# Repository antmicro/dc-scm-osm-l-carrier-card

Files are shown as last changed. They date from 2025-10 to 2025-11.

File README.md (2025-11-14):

# DC-SCM Carrier Card for OSM-L SoMs

Copyright (c) 2025 [Antmicro](https://www.antmicro.com)




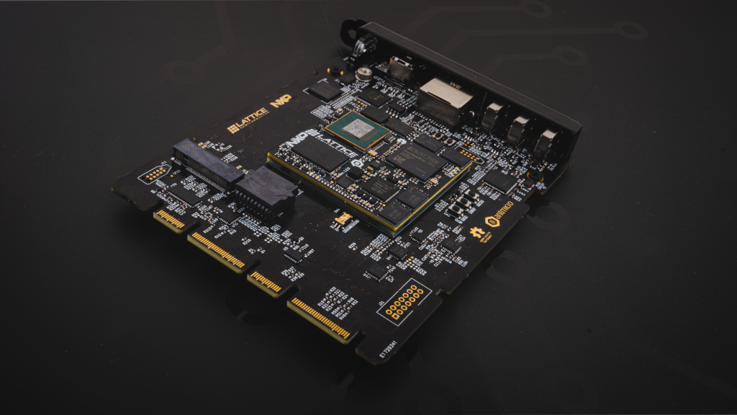
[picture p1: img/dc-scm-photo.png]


## Overview

This project includes open hardware design files for a DC-SCM compliant PCB that supports System on Modules following the [OSM-L](https://sget.org/standards/osm/) standard specified by the SGet group.
The DC-SCM follows the interface and mechanical outline described in the 2.1 revision of the [DC-SCM standard](https://drive.google.com/file/d/1-SdSQvSWy5pNN_kBiyztblxE4jdyUe9W/view?usp=sharing) specified by the Open Compute Project community.
Apart from establishing a base DC-SCM compliant platform, the design includes a series of breakout connectors, jumpers and other supplementary circuitry for developing BMC software features for security, reliability, commissioning and benchmarking.

This DC-SCM card has been designed as a carrier board to an L-sized [OSM design](https://github.com/antmicro/osm-l-bmc-som) that combines a Lattice FPGA and an NXP i.MX943 series Application Processor (AP).

The PCB design files were prepared in [KiCad](kicad.org/download) 9.x

## Key features

* Landing pad for OSM-L type of SoM
* Realtek 1Gb Ethernet PHY (Realtek [RTL8211FDI-CG](https://openhardware.antmicro.com/components/realtek-rtl8211fdi-cg))
* ITE [IT6251](https://openhardware.antmicro.com/components/ite-tech-it6251) LVDS-DisplayPort bridge
* USB-C port with FTDI [FT4232H](https://openhardware.antmicro.com/components/ftdi-chip-ft4232h-56q-reel/) for SoM debug and software integration
* USB-C port connected to the OSM-L SoM pads
* USB-C port connected to the HPM
* M.2 (key-M) expansion slot connected to the HPM
* Slot for removable BIOS memories connected directly to the HPM
* Optional on-board TPM connector

## Project structure

The main directory contains KiCad PCB project files, a LICENSE and a README.
The remaining files are stored in the following directories:

* `doc` - contains board schematic
* `img` contains graphics for this README

## Licensing

This project is published under the [Apache-2.0](LICENSE) license.

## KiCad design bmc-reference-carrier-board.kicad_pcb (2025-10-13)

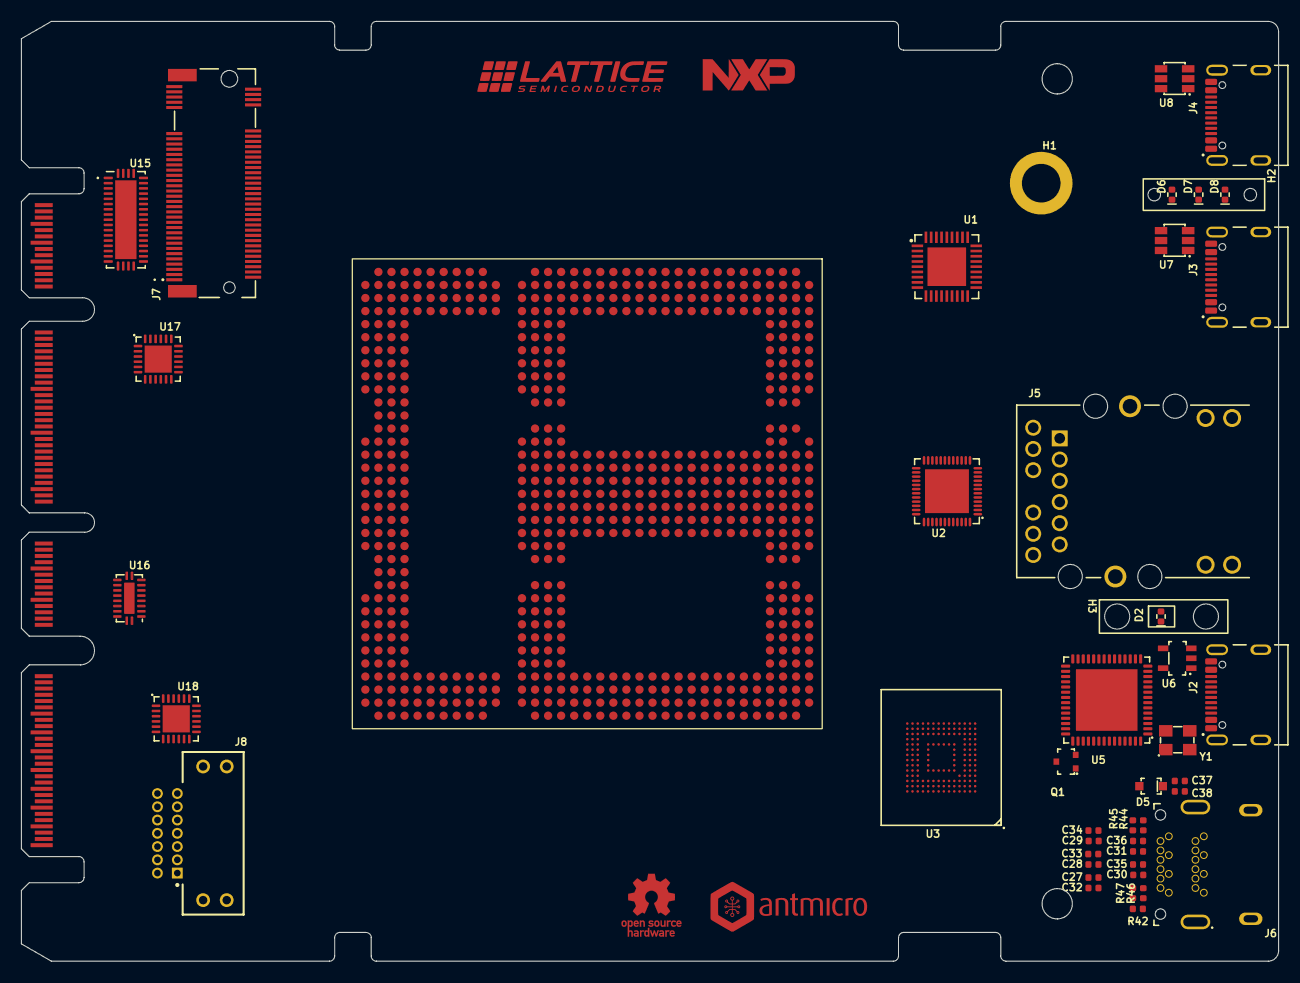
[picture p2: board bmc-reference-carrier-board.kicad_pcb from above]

Board: 8 copper layers, 120.4 x 90.0 mm, 47 parts (0 on the bottom side), 64 nets, no tracks yet.

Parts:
C27, C28, C29, C30, C31, C32, C33, C34, C35, C36: C_100n_0402; C_0402_1005Metric
C37, C38: C_4u7_6.3V_0402; C_0402_1005Metric
D2, D6, D7, D8: LED_G_0402_VLMTG1500-GS08; LED_0402_1005Metric_G
D5: 1N4148WS-7-F; D_SOD-323
H1: Spacer_Drill3.7mm_H2.5mm_9774025151R
H2: Lightpipe_Mentor_1296.2013; Mech_Lightpipe_Mentor_1296.2013
H3: Lightpipe_Mentor_1271.1000; Mech_Lightpipe_Mentor_1271.1000
J1: PCB-Edge_DC-SCM-2.1_2x84_Rev-1-1; PCB-Edge_DC-SCM_2x84_Rev-1-0
J2, J3, J4: USB-C_GCT_USB4105-GF-A; USB-C_Receptacle_GCT_USB4105-GF-A
J5: L834-1G1T-S7; RJ45_BEL_L834-1G1T-S7
J6: DisplayPort-Mini_TE_2129320-3; DisplayPort-Mini_Receptacle_TE_2129320-3
J7: Bus_M.2_1-2199230-6; Bus_M.2_Socket_Key_M_TE_1-2199230-6
J8: TFM-107-01-X-D-RE1-WT; Socket_Samtec_TFM_2x7_TFM-107-01-X-D-RE1-WT
Q1: BSS84AKW; SOT-323
R42: R_51k_0402; R_0402_1005Metric
R44, R45: R_100k_0402; R_0402_1005Metric
R46, R47: R_1M_0402; R_0402_1005Metric
U1: USB2514B-I_M2; QFN-36-1EP_6x6mm_P0.5mm_EP3.7x3.7mm
U2: RTL8211FS-CG; QFN-48-1EP_6x6mm
U3: SDINBDG4-8G; BGA-196-153_11.5x13mm_Layout14x14_P0.5x0.5mm
U5: FT4232H_VQFN; QFN-56-1EP_8x8mm_P0.5mm
U6: NCP718BSN330T1G; SOT-23-5
U7, U8: AP22615A_TSOT26; TSOT23-6
U14: OSM-L_Carrier-side
U15: TMUXHS4412RUAR; WQFN-42-1EP_3.5x9mm_P0.5mm
U16: TMUXHS4212IRKSR; VQFN-20_1EP_4.5x2.5mm_P0.5mm
U17, U18: TS3A27518E_QFN; QFN-24-1EP_4x4mm_P0.5mm_EP2.6x2.6mm
Y1: Resonator_12MHz_ABM8G; Resonator_SMD_Abracon_ABM8G_3.2x2.5mm

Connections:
+5V: U7.6 (IN), U8.6 (IN)
/DC-SCM 2.1 connector/DC_SCM_12V_AUX: J1.A1 (P12V_AUX), J1.A2 (P12V_AUX), J1.A3 (P12V_AUX), J1.A4 (P12V_AUX)
/DC-SCM 2.1 connector/DC_SCM_P3V0: J1.B28 (P3V0_HPM_SCM_BAT), U14.W17 (RTC_PWR)
/DC-SCM 2.1 connector/DC_SCM_PRSNT0_N: J1.A7 (PRSNT1_HPM_SCM_N), J1.B58 (PRSNT0_SCM_HPM_N)
/DC-SCM 2.1 connector/DC_SCM_USB1.D+: J3.A6 (D_{A}+), J3.B6 (D_{B}+)
/DC-SCM 2.1 connector/DC_SCM_USB1.D-: J3.A7 (D_{A}-), J3.B7 (D_{B}-)
/Ethernet PHY/ETHERNET.MDI0+: J5.11 (TRD1+), U2.2 (MDIP0)
/Ethernet PHY/ETHERNET.MDI0-: J5.10 (TRD1-), U2.3 (MDIN0)
/Ethernet PHY/ETHERNET.MDI1+: J5.4 (TRD2+), U2.5 (MDIP1)
/Ethernet PHY/ETHERNET.MDI1-: J5.5 (TRD2-), U2.6 (MDIN1)
/Ethernet PHY/ETHERNET.MDI2+: J5.3 (TRD3+), U2.7 (MDIP2)
/Ethernet PHY/ETHERNET.MDI2-: J5.2 (TRD3-), U2.8 (MDIN2)
/Ethernet PHY/ETHERNET.MDI3+: J5.8 (TRD4+), U2.10 (MDIP3)
/Ethernet PHY/ETHERNET.MDI3-: J5.9 (TRD4-), U2.11 (MDIN3)
/Front panel USB/FTDI_3V3: Q1.2 (S), U5.16 (V_{CCIO}), U5.36 (V_{CCIO}), U5.44 (V_{REGIN}), U5.50 (V_{CCIO}), U6.5 (VOUT)
/Front panel USB/USB0_VBUS: J3.A4 (VBUS), J3.A9 (VBUS), J3.B4 (VBUS), J3.B9 (VBUS), U7.1 (OUT)
/Front panel USB/USB1.D+: J4.A6 (D_{A}+), J4.B6 (D_{B}+)
/Front panel USB/USB1.D-: J4.A7 (D_{A}-), J4.B7 (D_{B}-)
/Front panel USB/USB1_VBUS: J4.A4 (VBUS), J4.A9 (VBUS), J4.B4 (VBUS), J4.B9 (VBUS), U8.1 (OUT)
/Front panel USB/USB2_D+: J2.A6 (D_{A}+), J2.B6 (D_{B}+), U5.8 (D+)
/Front panel USB/USB2_D-: J2.A7 (D_{A}-), J2.B7 (D_{B}-), U5.7 (D-)
/Front panel USB/USB2_VBUS: J2.A4 (VBUS), J2.A9 (VBUS), J2.B4 (VBUS), J2.B9 (VBUS), U6.1 (VIN), U6.3 (EN)
/Front panel USB/VCORE: U5.2 (V_{CORE}), U5.31 (V_{CORE}), U5.43 (V_{REGOUT})
/Front panel USB/XI: U5.3 (OSCI), Y1.1
/Front panel USB/XO: U5.4 (OSCO), Y1.3
/Front panel Video/AUX+: C31.1, J6.16 (AUX+), R45.2
/Front panel Video/AUX-: C36.1, J6.18 (AUX-), R44.1
/Front panel Video/CFG1: J6.4 (CFG1), R46.2
/Front panel Video/CFG2: J6.6 (CFG2), R47.2
/Front panel Video/DP_PWR: C37.2, C38.2, D5.1 (C), J6.20 (DP_PWR), R44.2
/Front panel Video/HPD: J6.2 (HPD), R42.1
/Front panel Video/TXD0+: C27.1, J6.3 (TXD0+)
/Front panel Video/TXD0-: C32.1, J6.5 (TXD0-)
/Front panel Video/TXD1+: C28.1, J6.9 (TXD1+)
/Front panel Video/TXD1-: C33.1, J6.11 (TXD1-)
/Front panel Video/TXD2+: C29.1, J6.15 (TXD2+)
/Front panel Video/TXD2-: C34.1, J6.17 (TXD2-)
/Front panel Video/TXD3+: C30.1, J6.10 (TXD3+)
/Front panel Video/TXD3-: C35.1, J6.12 (TXD3-)
/PCIe - SGMII Mux/PCIE_x4.RX1+: J7.31 (PER1_P), U15.34 (DA1P)
/PCIe - SGMII Mux/PCIE_x4.RX1-: J7.29 (PER1_N), U15.33 (DA1N)
/PCIe - SGMII Mux/PCIE_x4.RX2+: J7.19 (PER2_P), U15.25 (DA3P)
/PCIe - SGMII Mux/PCIE_x4.RX2-: J7.17 (PER2_N), U15.24 (DA3N)
/PCIe - SGMII Mux/PCIE_x4.TX1+: J7.37 (PET1_P), U15.38 (DA0P)
/PCIe - SGMII Mux/PCIE_x4.TX1-: J7.35 (PET1_N), U15.37 (DA0N)
/PCIe - SGMII Mux/PCIE_x4.TX2+: J7.25 (PET2_P), U15.29 (DA2P)
/PCIe - SGMII Mux/PCIE_x4.TX2-: J7.23 (PET2_N), U15.28 (DA2N)
/PCIe - SGMII Mux/VCC: U15.5 (VCC), U15.13 (VCC)
GND: C37.1, C38.1, J1.A5 (GND), J1.A6 (GND), J1.A19 (GND), J1.A22 (GND), J1.A25 (GND), J1.A29 (GND), J1.A32 (GND), J1.A35 (GND), J1.A38 (GND), J1.A53 (GND), J1.A64 (GND), J1.A67 (GND), J1.A70 (GND), J1.B11 (GND), J1.B19 (GND), J1.B22 (GND), J1.B25 (GND), J1.B29 (GND), J1.B32 (GND), J1.B35 (GND), J1.B38 (GND), J1.B64 (GND), J1.B67 (GND), J1.B70 (GND), J1.OA1 (GND), J1.OA4 (GND), J1.OA7 (GND), J1.OA10 (GND), J1.OA13 (GND), J1.OB1 (GND), J1.OB4 (GND), J1.OB7 (GND), J1.OB10 (GND), J1.OB13 (GND), J2.A1 (GND), J2.A12 (GND), J2.B1 (GND), J2.B12 (GND), J3.A1 (GND), J3.A12 (GND), J3.B1 (GND), J3.B12 (GND), J4.A1 (GND), J4.A12 (GND), J4.B1 (GND), J4.B12 (GND), J6.1 (GND), J6.7 (GND), J6.8 (GND), J6.13 (GND), J6.14 (GND), J6.19 (GND), J6.SH, R45.1, R46.1, R47.1, U3.A6 (VSS), U3.C4 (VSSQ), U3.E7 (VSS), U3.G5 (VSS), U3.H10 (VSS), U3.J5 (VSS), U3.K8 (VSS), U3.N2 (VSSQ), U3.N5 (VSSQ), U3.P4 (VSSQ), U3.P6 (VSSQ), U5.10 (TEST), U5.21 (GND), U5.41 (GND), U5.45 (GND), U5.57 (GND), U6.2 (GND), U7.2 (GND), U8.2 (GND), U15.6 (GND), U15.9 (GND), U15.16 (GND), U15.21 (GND), U15.30 (GND), U15.39 (GND), U15.43 (GND), U16.5 (GND), U16.11 (GND), U16.20 (GND), U16.21 (GND), Y1.2 (SH), Y1.4 (SH)
unnamed: D2.2 (A), Q1.3 (D)
unnamed: J5.1 (TRCT3), J5.6 (TRCT2), J5.7 (TRCT4), J5.12 (TRCT1)
unnamed: J7.2 (3V3), J7.4 (3V3), J7.12 (3V3), J7.14 (3V3), J7.16 (3V3), J7.18 (3V3), J7.70 (3V3), J7.72 (3V3), J7.74 (3V3)
unnamed: J7.1 (GND), J7.3 (GND), J7.9 (GND), J7.15 (GND), J7.21 (GND), J7.27 (GND), J7.33 (GND), J7.39 (GND), J7.45 (GND), J7.51 (GND), J7.57 (GND), J7.71 (GND), J7.73 (GND), J7.75 (GND)
unnamed: J7.MP1 (MP), J7.MP2 (MP)
unnamed: Q1.1 (G), U5.54 (~PWR_{EN})
unnamed: U1.15 (VDD33), U1.23 (VDD33)
unnamed: U1.5 (VDDA33), U1.10 (VDDA33), U1.29 (VDDA33), U1.36 (VDDA33)
unnamed: U2.4 (AVDD10), U2.9 (AVDD10), U2.47 (AVDD10)
unnamed: U2.1 (AVDD33), U2.12 (AVDD33), U2.30 (AVDD33)
unnamed: U3.E6 (VCC), U3.F5 (VCC), U3.J10 (VCC), U3.K9 (VCC)
unnamed: U3.C6 (VCCQ), U3.M4 (VCCQ), U3.N4 (VCCQ), U3.P3 (VCCQ), U3.P5 (VCCQ)
unnamed: U14.A4 (GND), U14.A7 (GND), U14.A10 (GND), U14.A26 (GND), U14.A29 (GND), U14.A32 (GND), U14.AA1 (GND), U14.AA4 (GND), U14.AA7 (GND), U14.AA8 (GND), U14.AA10 (GND), U14.AA11 (GND), U14.AA14 (GND), U14.AA17 (GND), U14.AA19 (GND), U14.AA22 (GND), U14.AA25 (GND), U14.AA26 (GND), U14.AA27 (GND), U14.AA28 (GND), U14.AA32 (GND), U14.AB3 (GND), U14.AB6 (GND), U14.AB9 (GND), U14.AB15 (GND), U14.AB21 (GND), U14.AB28 (GND), U14.AB31 (GND), U14.AB34 (GND), U14.AC4 (GND), U14.AC7 (GND), U14.AC10 (GND), U14.AC27 (GND), U14.AC30 (GND), U14.AC33 (GND), U14.AE2 (GND), U14.AE34 (GND), U14.AF35 (GND), U14.AG3 (GND), U14.AH2 (GND), U14.AH34 (GND), U14.AJ35 (GND), U14.AK3 (GND), U14.AL2 (GND), U14.AL34 (GND), U14.AM13 (GND), U14.AM16 (GND), U14.AM19 (GND), U14.AM22 (GND), U14.AM35 (GND), U14.AN3 (GND), U14.AN6 (GND), U14.AN9 (GND), U14.AN11 (GND), U14.AN15 (GND), U14.AN18 (GND), U14.AN21 (GND), U14.AN33 (GND), U14.AP2 (GND), U14.AP5 (GND), U14.AP8 (GND), U14.AP13 (GND), U14.AP16 (GND), U14.AP19 (GND), U14.AP22 (GND), U14.AP25 (GND), U14.AP28 (GND), U14.AP31 (GND), U14.AP34 (GND), U14.AR14 (GND), U14.AR17 (GND), U14.AR20 (GND), U14.AR26 (GND), U14.AR29 (GND), U14.AR32 (GND), U14.B2 (GND), U14.B5 (GND), U14.B8 (GND), U14.B9 (GND), U14.B27 (GND), U14.B28 (GND), U14.B30 (GND), U14.B33 (GND), U14.C11 (GND), U14.C25 (GND), U14.C32 (GND), U14.C35 (GND), U14.D1 (GND), U14.D5 (GND), U14.D8 (GND), U14.D18 (GND), U14.D28 (GND), U14.D34 (GND), U14.E2 (GND), U14.E15 (GND), U14.E21 (GND), U14.F16 (GND), U14.F20 (GND), U14.F33 (GND), U14.F35 (GND), U14.G34 (GND), U14.H2 (GND), U14.H4 (GND), U14.H32 (GND), U14.J16 (GND), U14.J20 (GND), U14.J33 (GND), U14.J35 (GND), U14.K32 (GND), U14.K34 (GND), U14.L2 (GND), U14.L4 (GND), U14.L18 (GND), U14.M16 (GND), U14.M20 (GND), U14.M32 (GND), U14.M35 (GND), U14.N34 (GND), U14.P2 (GND), U14.P4 (GND), U14.P18 (GND), U14.R1 (GND), U14.R16 (GND), U14.R20 (GND), U14.R32 (GND), U14.T34 (GND), U14.U2 (GND), U14.U4 (GND), U14.V1 (GND), U14.V16 (GND), U14.V20 (GND), U14.W3 (GND), U14.W34 (GND), U14.Y2 (GND), U14.Y18 (GND)
unnamed: U14.AE4 (VCC_IN_5V), U14.AF4 (VCC_IN_5V), U14.AG4 (VCC_IN_5V), U14.AH3 (VCC_IN_5V), U14.AH4 (VCC_IN_5V), U14.AJ3 (VCC_IN_5V), U14.AJ4 (VCC_IN_5V), U14.AK4 (VCC_IN_5V), U14.Y8 (VCC_IN_5V), U14.Y9 (VCC_IN_5V), U14.Y10 (VCC_IN_5V), U14.Y11 (VCC_IN_5V), U14.Y17 (VCC_IN_5V), U14.Y25 (VCC_IN_5V), U14.Y26 (VCC_IN_5V), U14.Y27 (VCC_IN_5V), U14.Y28 (VCC_IN_5V)
unnamed: U14.AA18 (V_BAT), U14.AB18 (V_BAT)

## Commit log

2025-08-19 [#81876] Create KiCad file structure. Define DC-SCM 2.1 edge and outline
    [bmc-reference-carrier-board.kicad_pcb, bmc-reference-carrier-board.kicad_sch, dc-scm-connector.kicad_sch]
2025-08-19 [#81876] Add component and tracks keepout as defined in DC-SCM 2.1 spec
    [bmc-reference-carrier-board.kicad_pcb]
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2025-10-13 [#81876] Update date, Regroup OSM L block to make it interchangeable
    [bmc-reference-carrier-board.kicad_sch, dc-scm-connector.kicad_sch, dsi-to-dp-converter.kicad_sch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]
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2025-10-13 [#81978] Fix subsheet file naming
    [bmc-reference-carrier-board.kicad_sch, front-panel-low-speed.kicad_sch, front-panel-usb.kicad_sch]
2025-10-13 [#81876] Replace OSM blocks with single A2 sheet
    [bmc-reference-carrier-board.kicad_sch, osm-l.kicad_sch, osm_l.kicad_sch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]
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2025-10-13 [#81876] Hierarchical design review fixes
    [bmc-reference-carrier-board.kicad_sch, dsi-to-dp-converter.kicad_sch, lvds-to-dp-converter.kicad_sch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]
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2025-10-13 [#82153] Move Ethernet bus definition to root schematic
    [bmc-reference-carrier-board.kicad_sch, front-panel-ethernet.kicad_sch]
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2025-10-13 [#81876] Join sheets: Front panel USB and Front panel Low Speed
    [bmc-reference-carrier-board.kicad_sch, front-panel-low-speed.kicad_sch, front-panel-usb.kicad_sch]
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2025-10-13 [#82153] Fix LED2 label on ETH sheet
    [front-panel-ethernet.kicad_sch]
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2025-10-13 [#82157] Labels on root sheet from Ethernet and video sheets
    [bmc-reference-carrier-board.kicad_sch]
2025-10-13 [#81876] Add bus definitions for JTAG and UART
    [front-panel-usb.kicad_sch]
2025-10-13 [#81876] Add FTDI chip, DBG USB and LDO
    [front-panel-usb.kicad_sch]
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2025-10-13 [#82157] Move JTAG and UART definitions to root sheet
    [bmc-reference-carrier-board.kicad_sch, front-panel-usb.kicad_sch]
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2025-10-13 [#82176] Fix conflicting annotations
    [emmc.kicad_sch, eth-phy.kicad_sch, front-panel-ethernet.kicad_sch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]
2025-10-13 [#82176] Add bus definitions for PCIe and USB SS
    [bmc-reference-carrier-board.kicad_sch]
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2025-10-13 [#82148] Replace PCIe/USB mux with TMUXHS4212IRKSR
    Update PCIe/USB mux sheet
    [pcie-usb-mux.kicad_sch]
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2025-10-13 Replace {slash} with _
    [dc-scm-connector.kicad_sch]
2025-10-13 [#82226] Extend PCIe bus definition to x4. Update hierarchical pins
    [bmc-reference-carrier-board.kicad_sch]
2025-10-13 [#82226] Add PCIe connection to PCIe x4 connector
    [pcie-x4-connector.kicad_sch]
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2025-10-13 Replace USB-C connectors with vertical version
    [front-panel-usb.kicad_sch]
2025-10-13 Replace Eth connector with 7498111120R
    [bmc-reference-carrier-board.kicad_sch, front-panel-ethernet.kicad_sch]
2025-10-13 Replace Mini DP connector with E9320-001-01
    [front-panel-video.kicad_sch]
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2025-10-13 Change USB0 and USB1 to advertise as 500mA source
    [front-panel-usb.kicad_sch]
2025-10-13 [#82176] Import components from schematic and create initial placement
    [bmc-reference-carrier-board.kicad_pcb]
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2025-10-13 [#82323] Add IxC, LTPI, SGMII, RGMII, SPI, eSPI, QSPI buses definitions
    [bmc-reference-carrier-board.kicad_sch]
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2025-10-13 [#82323] Connect NC-SI, QSPI, LTPI and UART buses to DC-SCM
    [dc-scm-connector.kicad_sch]
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2025-10-13 [#82323] Connect JTAG, USB, TPM, IxC and SPI buses to DC-SCM
    [dc-scm-connector.kicad_sch]
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2025-10-13 [#82323] Connect SDIO to OSM, prepare LVDS connections
    [osm-l.kicad_sch]
2025-10-13 [#82323] Update OSM connections
    Move LTPI to LVSD pins
    Move I2C 0/1/2/3 lanes to vendor defined pins
    Move I2C/I3C 16/17 to GPIOD
    Add ~PRSNT1 as GPIO_A_3
    Add ~IRQ0 as GPIO_A_2
    Add ~STDB_RDY as GPIO_A_1
    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
    [osm-l.kicad_sch]
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2025-10-13 [#82341] LVDS/DP Bridge: Add 1V2 and 1V8 LDOs
    [lvds-to-dp-converter.kicad_sch]
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2025-10-13 [#83147] Fix spi labels
    [lvds-to-dp-converter.kicad_sch, osm-l.kicad_sch]
2025-10-13 [#83146] Fix LTPI connection, add bias
    [bmc-reference-carrier-board.kicad_sch, ltpi-voltage-bias.kicad_sch, lvds-to-dp-converter.kicad_sch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]
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2025-10-13 [#82233] Added eSPI/QSPI mux and DNP QSPI flash memory
    [bios_qspi.kicad_sch, bmc-reference-carrier-board.kicad_sch, espi-qspi-mux.kicad_sch]
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2025-10-13 [#82176] eMMC: change chip to 32GB & add decoupling
    [bmc-reference-carrier-board.kicad_sch, emmc.kicad_sch]
2025-10-13 [#82176] Connect eMMC SDIO to OSM, annotate eMMC schematic
    [bmc-reference-carrier-board.kicad_sch, emmc.kicad_sch, osm-l.kicad_sch]
2025-10-13 [#83148] Add level shifters for i2c & stby
    [dc-scm-connector.kicad_sch, i2c_level_shifters.kicad_sch, stby_level_shifters.kicad_sch]
2025-10-13 [#83148] Connect the level shifters, change STBY bus to individual signals
    [bmc-reference-carrier-board.kicad_sch, dc-scm-connector.kicad_sch, i2c_level_shifters.kicad_sch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]
2025-10-13 Changed A4 sheets to A3 and cleaned them up
    [espi-qspi-mux.kicad_sch, front-panel-ethernet.kicad_sch, i2c_level_shifters.kicad_sch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]
2025-10-13 [#83363] Replaced 1V8 LDO with DC/DC and moved it to power sheet
    [lvds-to-dp-converter.kicad_sch, power.kicad_sch]
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2025-10-13 [#83338] Fixed PCIe TX/RX
    [dc-scm-connector.kicad_sch, pcie-sgmii-mux.kicad_sch, pcie-x4-connector.kicad_sch]
2025-10-13 [#83338] Fixed HS connection AC caps and TX/RX swaps
    [bmc-reference-carrier-board.kicad_sch, dc-scm-connector.kicad_sch, osm-l.kicad_sch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]
2025-10-13 [#83329] Connect LEDs, crystal resontor, MDIO and MDC to the ETH PHY
    [eth-phy.kicad_sch]
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2025-10-13 [#83329] Change ETH PHY IC from RTL8211FS-CG to RTL8211FDI-CG
    [eth-phy.kicad_sch]
2025-10-13 [#83329] Finish connecting ETH PHY, connect ETH LEDs, adjust PHY power supply filtering
    [eth-phy.kicad_sch, front-panel-ethernet.kicad_sch]
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2025-10-13 [#83329] Small ethernet PHY fixes
    [bmc-reference-carrier-board.kicad_sch, eth-phy.kicad_sch, front-panel-ethernet.kicad_sch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]
2025-10-13 [#83331] Added PECI circuitry. Small top fixes
    [bmc-reference-carrier-board.kicad_sch, dc-scm-connector.kicad_sch, eth-phy.kicad_sch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]
2025-10-13 [#83335] Change TPM connector to 2x7 pin header and connect it
    [tpm.kicad_sch]
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2025-10-13 [#83336] Small front panel interface fixes
    [bmc-reference-carrier-board.kicad_sch, espi-qspi-mux.kicad_sch, front-panel-ethernet.kicad_sch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]
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2025-10-13 [#82323] Small OSM pinout fixes
    [bmc-reference-carrier-board.kicad_sch, osm-l.kicad_sch]
2025-10-13 [#83362] Add headers to LTPI, PECI and I2C
    [dc-scm-connector.kicad_sch]
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2025-10-13 [#83362] Fix connections of headers, add I2C mux
    [bmc-reference-carrier-board.kicad_sch, dc-scm-connector.kicad_sch, fpga-devkit-conn.kicad_sch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]
2025-10-13 [#83362] Remove bad NC marks, small visual fixes
    [fpga-devkit-conn.kicad_sch]
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2025-10-13 [#83652] Add ability to program BIOS SPI flash
    [bios_qspi.kicad_sch, espi-qspi-mux.kicad_sch]
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2025-10-13 [#83609] Connect PWR_EN signal, change eMMC power to AON, minor schematic refactor
    [bmc-reference-carrier-board.kicad_sch, emmc.kicad_sch, power.kicad_sch]
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2025-10-13 [#83736] Fix overlaping text and graphics, fix notes regarding USB-C role
    [front-panel-usb.kicad_sch, front-panel-video.kicad_sch]
2025-10-13 [#83736] Change the 5V DC-DC conveter with more powerful one, refactor power schematic sheet
    [power.kicad_sch]
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2025-10-13 [#83767] Change USB-C connectors to ones on the PCB, sync PCB with schematic
    [front-panel-usb.kicad_sch, lvds-to-dp-converter.kicad_sch]
2025-10-13 [#83767] Layout DC-DC converters, change 0R on power rails to one that can handle more current
    [power.kicad_sch]
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2025-10-13 [#83767] Fix SDIO net class assignment, synchronize PCB with schematic
    [emmc.kicad_sch, osm-l.kicad_sch]
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2025-10-13 [#83767] Fix overlaping graphics, add termination to RX_E1
    [espi-qspi-mux.kicad_sch, lvds-to-dp-converter.kicad_sch]
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2025-10-13 [#83767] Replace USB Hub clk generator with crystal to align with reference design
    [usb-hub.kicad_sch]
2025-10-13 [#83767] Add alternative reset signal
    [bmc-reference-carrier-board.kicad_sch, front-panel-usb.kicad_sch, osm-l.kicad_sch]
2025-10-13 [#83767] Add USB SS RX/TX swap note
    [pcie-usb-mux.kicad_sch]
2025-10-13 [#83767] Fix U5 SEL signal voltage
    [pcie-usb-mux.kicad_sch]
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2025-10-13 [#83767] Add SGMII RX/TX swap note
    Fix signal level on U26 SEL pin
    [bmc-reference-carrier-board.kicad_sch, pcie-sgmii-mux.kicad_sch, pcie-x4-connector.kicad_sch]
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2025-10-13 [#83767] Replace BIOS flash with SO-16 package
    [bios_qspi.kicad_sch]
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2025-10-13 [#83767] Connect ESD only to USB data lines
    CC lines have ESD inside CC controller
    [front-panel-usb.kicad_sch, usb-hub.kicad_sch]
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2025-10-13 [#83767] Remove redundant OSM 0R on LTPI
    Bias circuitry can be used as path selection
    [osm-l.kicad_sch]
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2025-10-13 [#83767] Replace 0201 resistors with 0402
    [front-panel-usb.kicad_sch]
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2025-10-13 [#83767] Replace RTL8211FDI-CG oscillator
    [eth-phy.kicad_sch]
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2025-10-13 [#83767] Change TPM connector to one with correct pitch
    [tpm.kicad_sch]
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2025-10-13 [#84768] Add missing connections on sch
    [front-panel-usb.kicad_sch, ftdi_level_shifters.kicad_sch, osm-l.kicad_sch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]
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2025-10-14 Update naming on schematics, fix OSM page size
    [bmc-reference-carrier-board.kicad_sch, dc-scm-connector.kicad_sch, espi-qspi-mux.kicad_sch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]
2025-11-06 Swap +5V DC/DC inductor to low profile
    [power.kicad_sch]
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2025-11-13 Fix missing connections. Clean ERC
    [espi-qspi-mux.kicad_sch, eth-phy.kicad_sch, front-panel-usb.kicad_sch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]
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

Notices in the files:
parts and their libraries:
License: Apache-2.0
